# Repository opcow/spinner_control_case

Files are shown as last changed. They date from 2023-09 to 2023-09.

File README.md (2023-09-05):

# Spinner Control Case

A case for a spinner control for retro arcade games. A work in progress.

The case lid can be flipped for right handed or left handed spinner operation. The button assembly uses micro switches taken from an old mouse. RIP MX518. You served me well.

All parts were printed with a 0.4 mm nozzle. All holes were sized for threaded inserts for M3 and M2.5 screws. STEP files are provided if you need to make adjustments.

I've included a fit test model for the microswitch slots that can be printed before printing the full microswitch carrier. You want the switch to fit snugly, but bear in mind that if it the fit is really tight then it's going to force the sides of the slot outward making the adjacent slots even tighter.

The optical encoder I used does not tolerate less that 5v input. My Arduino was supplying a bit under 5v and I was testing using the full length leads to the encoder. When testing without the boost converter the encoder did not work. My converter output is set to 8v.

## Optional Things

I chose to mount the MCU with header pins installed because it helps to hold it solidly in place. The MCU gets sandwiched between the MCU cover and the mount which is screwed to the bottom cover and the whole thing is held together using a zip tie. There is also a mount meant to be used without the cover, just a zip tie holding the board in place. If you use a different MCU than the one I used then you may need to make your own solution for mounting.

Likewise, the front cover is designed to fit my MCU. Modify if needed.

There is a mount with cover for the booster to snap into, but these things come in various shapes. I don't use the cover and I stick the mount to the bottom case cover with a 3M double-sided stickie. You could just stick the booster directly to the bottom cover.

If you don't use threaded inserts then you will want to resize the holes. For quality heat set inserts and tools I recommend [CNC Kitchen](https://www.cnckitchen.com/) (I am not affiliated). They sell quality products and ship promptly in my experience.

There are 2 bottom cover options. The thinner one saves 3mm. The thicker one should be able to accommodate the encoder without its case removed, but you will probably need to rotate the encoder screw holes to avoid interference. I recommend removing the encoder's metal case; it just makes everything easier and you can verify the wiring that way.

## Firmware

The firmware running on the spinner is based on [Wilfried JEANNIARD's repo](https://github.com/willoucom/Arduino_ArcadeSpinner), modified to allow the spinner to act as a DPAD. While holding down button 1 press button 4 then release both buttons. There will be a 1 second delay and then scroll mode will be toggled. While in scroll mode the spinner will send `DPAD UP` presses to the host when turned clockwise and `DPAD DOWN` presses when turned counter-clockwise. While holding button 4 the spinner will send `DPAD RIGHT` and `DPAD LEFT`.

To configure the spinner in the MiSTer UI do the following:

* Toggle scroling mode on
* Using a keyboard, enter the `define joystick buttons` function
* Hold button 4 on the spinner when asked to press `RIGHT` and turn the spinner CW
* When asked to press `DOWN`, release button 4 and turn the spinner counter-clockwise
* Skip the 2 tilt tests
* Hold button 4 and turn the spinner CW then CCW to define `RIGHT` AND `LEFT`
* Release button 4 then turn the spinner CCW then CW to define `DOWN` and `UP`
* Toggle scrolling mode off
* Press and release buttons 1-4 to define `A`, `B`, `X`, and `Y`
* Press enter on the keyboard to save the configuration

If you mess up during these steps press escape and try again.

## Links for parts I purchased for this project

* [Optical encoder](https://www.amazon.com/dp/B07MX1SYXB?ref=ppx_yo2ov_dt_b_product_details&th=1)
* [A less expensive optical encoder which should also work](https://www.amazon.com/dp/B00UTIFCVA/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)
* [Boost converter](https://www.amazon.com/dp/B0C858YYQ1?ref=ppx_yo2ov_dt_b_product_details&th=1)
* [Type-C USB Pro Micro ATmega32U4 5V 16MHz](https://www.amazon.com/dp/B0BCW67NJP?psc=1&ref=ppx_yo2ov_dt_b_product_details)

---
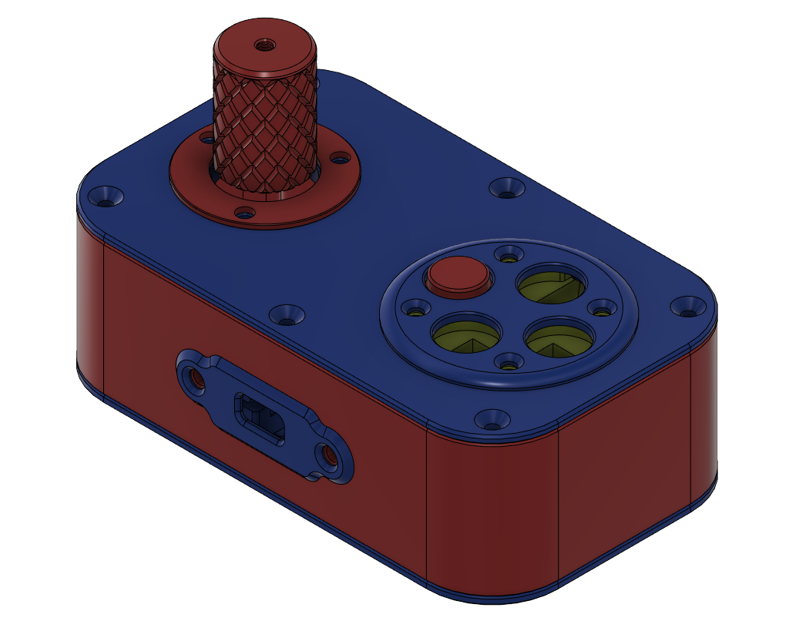
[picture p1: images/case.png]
case image

---
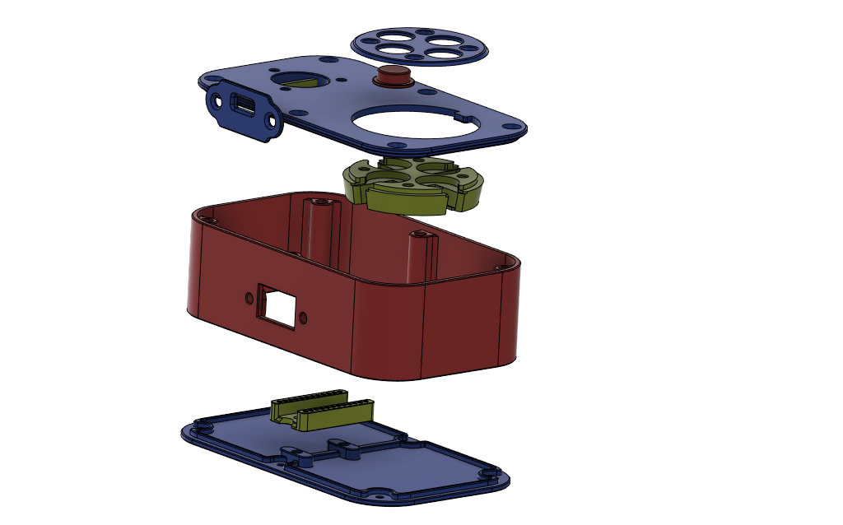
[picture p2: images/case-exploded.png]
exploded view

---
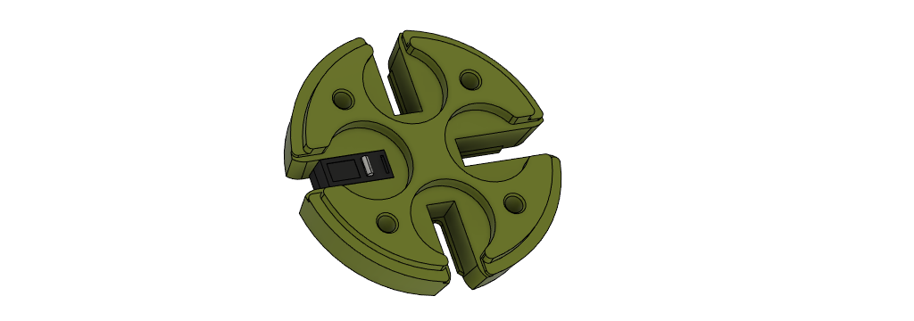
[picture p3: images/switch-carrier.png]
switch carrier

---
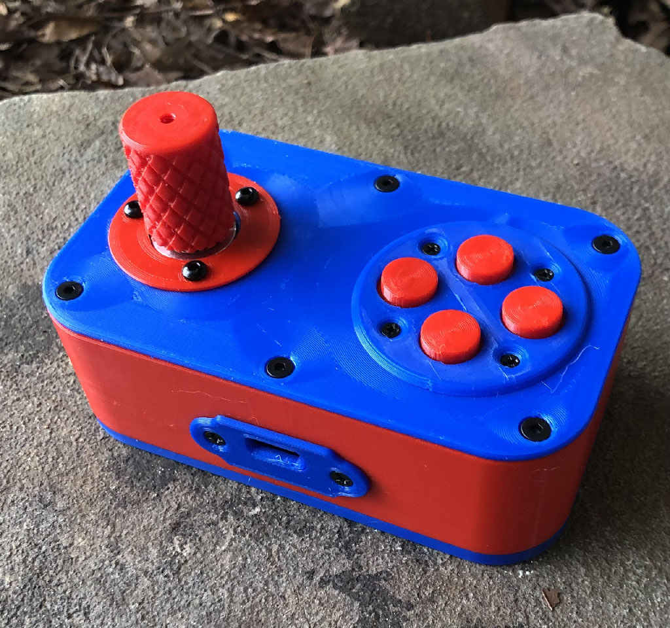
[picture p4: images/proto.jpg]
prototype


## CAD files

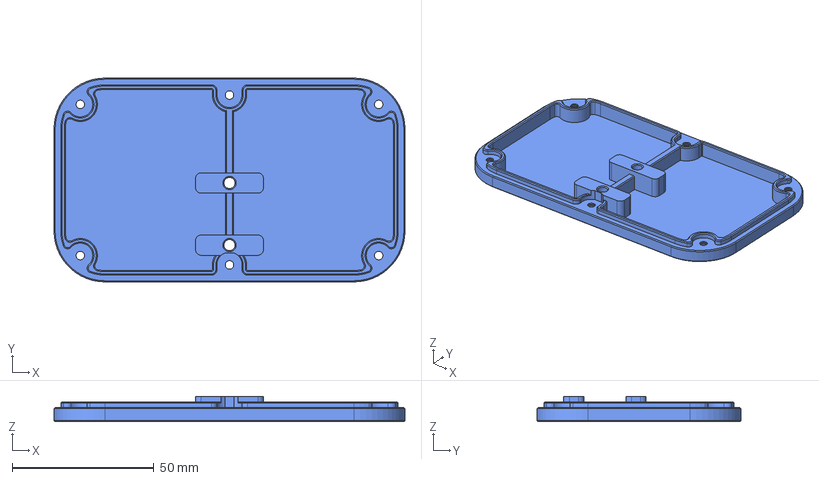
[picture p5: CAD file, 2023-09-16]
STEP/bottom-cover-a.step
124.0 x 72.0 x 9.00 mm

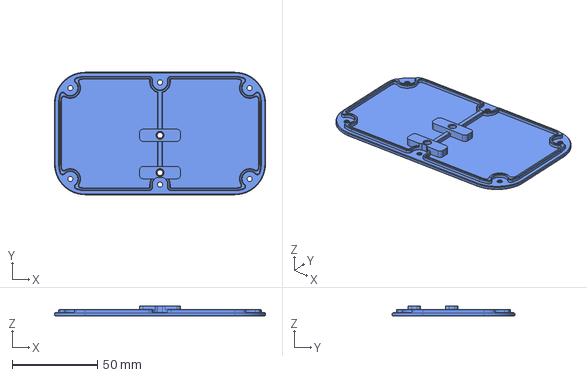
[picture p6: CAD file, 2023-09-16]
STEP/bottom-cover-b.step
124.0 x 72.0 x 6.00 mm

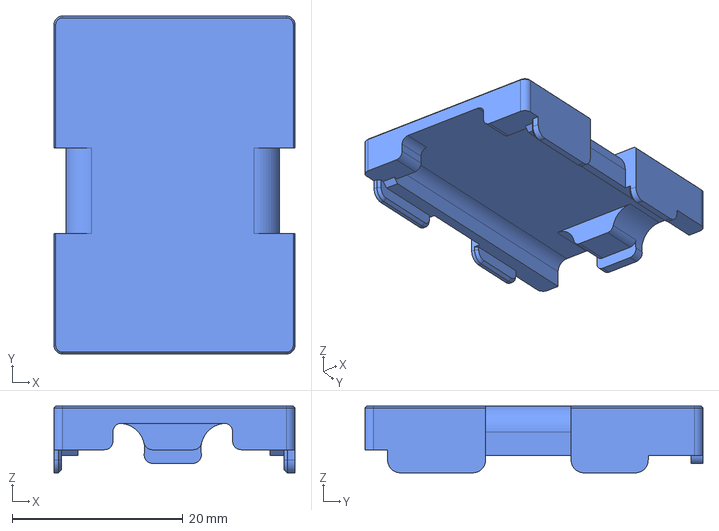
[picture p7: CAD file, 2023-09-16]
STEP/mcu-mount-c-cover.step
28.2 x 39.5 x 7.80 mm

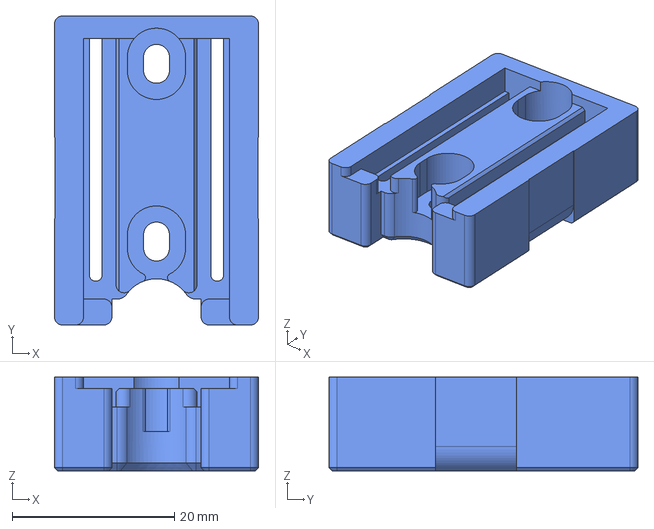
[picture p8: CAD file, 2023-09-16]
STEP/mcu-mount-c.step
25.2 x 38.1 x 11.6 mm

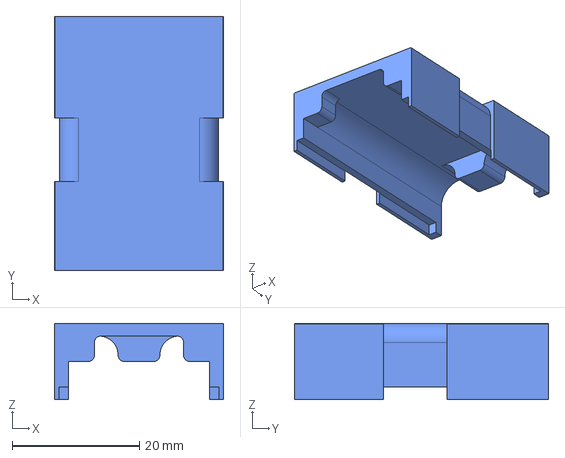
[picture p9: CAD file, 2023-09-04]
STEP/mcu-mount-b-cover.step
26.6 x 39.9 x 12.0 mm

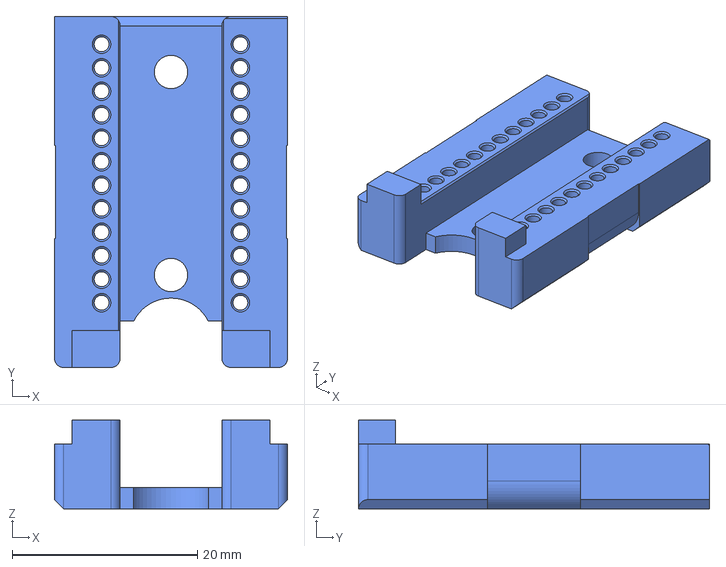
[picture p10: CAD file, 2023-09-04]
STEP/mcu-mount-b.step
25.2 x 37.9 x 9.60 mm

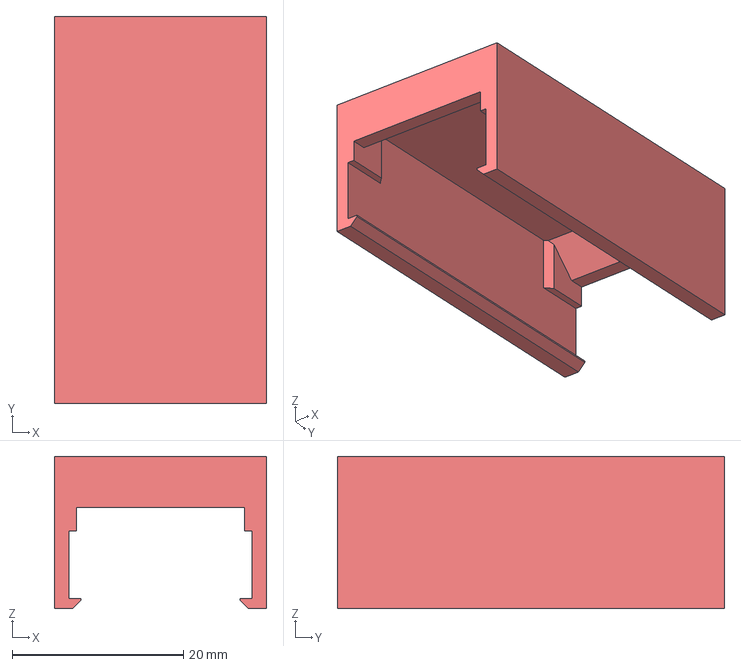
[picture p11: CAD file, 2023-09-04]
STEP/booster-cover.step
24.8 x 45.2 x 17.8 mm

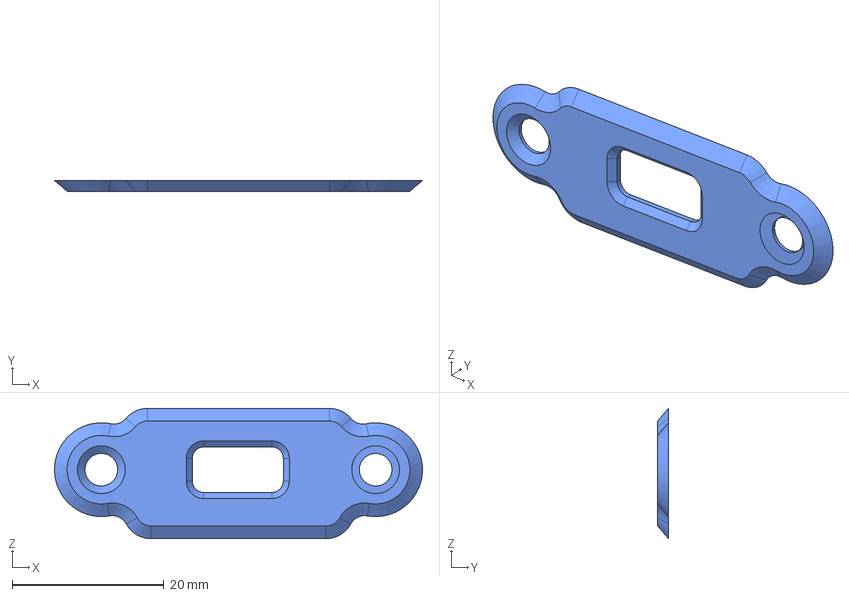
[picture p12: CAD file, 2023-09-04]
STEP/front-cover.step
48.6 x 1.40 x 17.2 mm

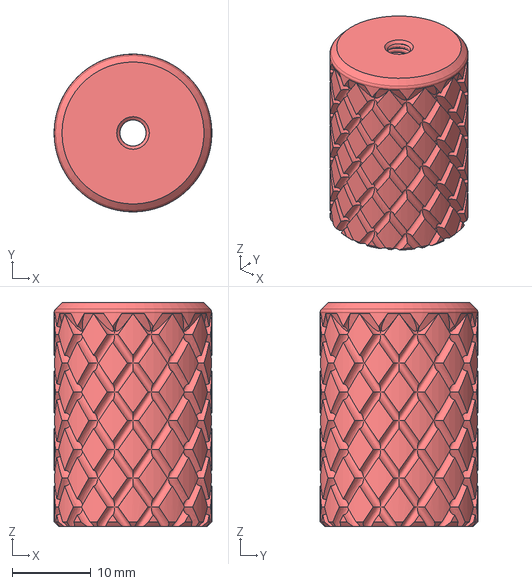
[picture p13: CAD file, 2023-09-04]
STEP/20mm-knob.step
20.0 x 20.0 x 28.4 mm

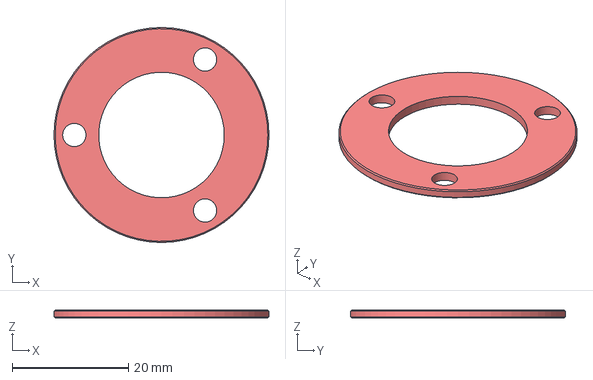
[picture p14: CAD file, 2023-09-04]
STEP/knob-ring.step
37.0 x 37.0 x 1.40 mm

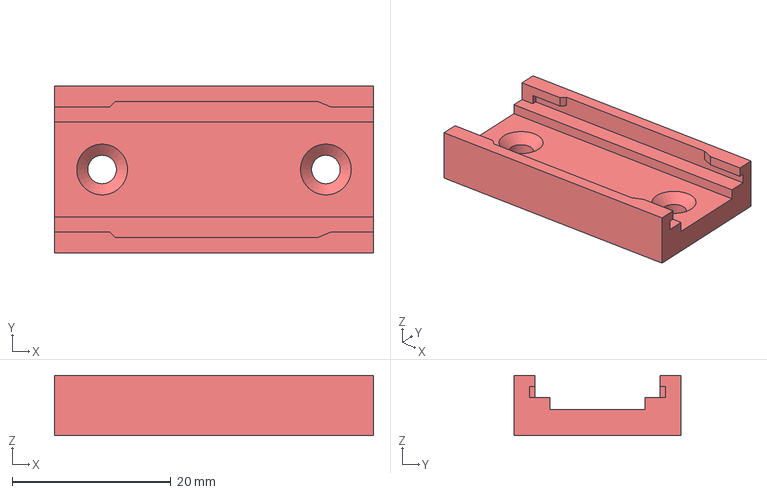
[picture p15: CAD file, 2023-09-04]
STEP/booster-mount.step
40.2 x 21.0 x 7.60 mm

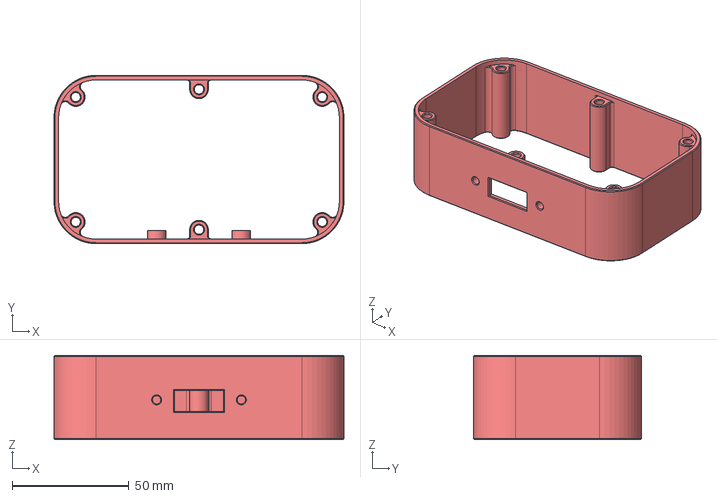
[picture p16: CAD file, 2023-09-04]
STEP/case.step
124.0 x 72.0 x 36.0 mm

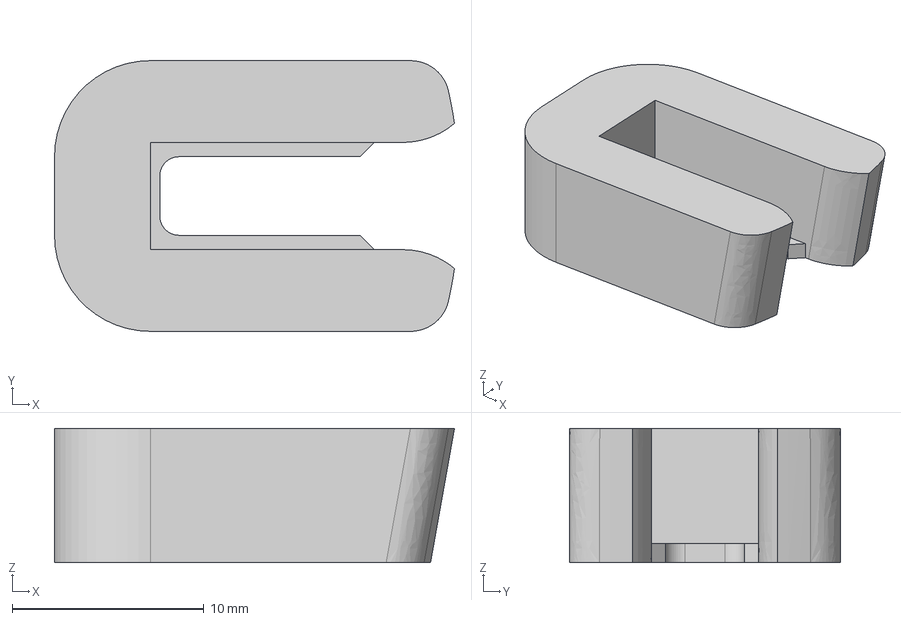
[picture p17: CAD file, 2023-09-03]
STEP/fit-test.step
20.9 x 14.1 x 7.00 mm

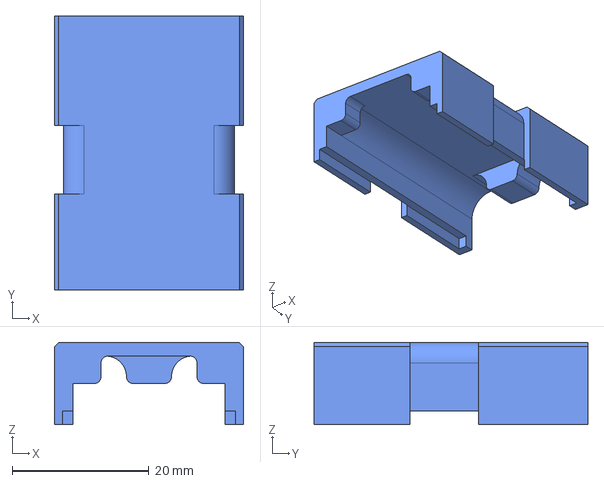
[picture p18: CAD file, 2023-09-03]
STEP/board-mount-b-cover.step
27.6 x 39.9 x 12.0 mm

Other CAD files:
STEP/mcu-mount-a.step
STEP/board-mount-b.step
STEP/button-cover.step
STEP/microswitch-carrier.step
STEP/12mm-button.step
STEP/top-cover.step
STL/12mm-button.stl
STL/booster-cover.stl
STL/booster-mount.stl
STL/bottom-cover-a.stl
STL/bottom-cover-b.stl
STL/button-cover.stl
STL/case.stl
STL/fit-test.stl
STL/front-cover.stl
STL/knob-ring.stl
STL/mcu-mount-a.stl
STL/mcu-mount-b-cover.stl
STL/mcu-mount-b.stl
STL/mcu-mount-c-cover.stl
STL/mcu-mount-c.stl
STL/microswitch-carrier.stl
STL/top-cover.stl
booster_mount.step
front_cover.step

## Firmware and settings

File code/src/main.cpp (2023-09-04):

/*
 *  Arduino USB Arcade Spinner
 *  (C) Wilfried JEANNIARD [https://github.com/willoucom]
 *
 *  Based on project by Alexey Melnikov [https://github.com/MiSTer-devel/Retro-Controllers-USB-MiSTer/blob/master/PaddleTwoControllersUSB/PaddleTwoControllersUSB.ino]
 *  Based on project by Mikael Norrgård <mick@daemonbite.com>
 *
 *  GNU GENERAL PUBLIC LICENSE
 *  Version 3, 29 June 2007
 *
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
 */

///////////////// Customizable settings /////////////////////////
// For debug (check serial monitor)
// #define DEBUG

// Spinner pulses per revolution
#define SPINNER_PPR 600

// Spinner/Mouse sensitivity
// 1 is more sensitive
// 999 is less sensitive
#define SPINNER_SENSITIVITY 2
#define MOUSE_SENSITIVITY 4

/////////////////////////////////////////////////////////////////

// Pins used by encoder
#define pinA 2
#define pinB 3
// Pins used by buttons
#define Button0 5  // Left button
#define Button1 4  // Right button
#define Button2 15 // Small Left: Select/Coin
#define Button3 14 // Small Right: Start

////////////////////////////////////////////////////////

// ID for special support in MiSTer
// ATT: 20 chars max (including NULL at the end) according to Arduino source code.
// Additionally serial number is used to differentiate arduino projects to have different button maps!
const char *gp_serial = "MiSTer-A1 Spinner";

#include <Mouse.h>
#include "Gamepad.h"

// Create Gamepad
Gamepad_ Gamepad;
GamepadReport rep;

// Default virtual spinner position
int16_t drvpos = 0;
// Default real spinner position
int16_t r_drvpos = 0;
// Default virtual mouse position
int16_t m_drvpos = 0;

// Variables for paddle_emu
#define SP_MAX ((SPINNER_PPR * 4 * 270UL) / 360)
int32_t sp_clamp = SP_MAX / 2;

// For emulation
bool mouse_emu = 0;
bool paddle_emu = 0;
bool mr_spinner_emu = 0;
bool scroll_mode = false;

void scroll(int16_t dir);

// Interrupt pins of Rotary Encoder
void drv_proc()
{
  static int8_t prev = drvpos;
  int8_t a = digitalRead(pinA);
  int8_t b = digitalRead(pinB);

  int8_t spval = (b << 1) | (b ^ a);
  int8_t diff = (prev - spval) & 3;

  if (diff == 1)
  {
    r_drvpos += 1;
    if (sp_clamp < SP_MAX)
      sp_clamp++;
  }
  if (diff == 3)
  {
    r_drvpos -= 1;
    if (sp_clamp > 0)
      sp_clamp--;
  }

  drvpos = r_drvpos / SPINNER_SENSITIVITY;
  m_drvpos = r_drvpos / MOUSE_SENSITIVITY;
  prev = spval;
}

// Run at startup
void setup()
{
  pinMode(LED_BUILTIN_TX, INPUT);
  pinMode(LED_BUILTIN_RX, INPUT);
#ifdef DEBUG
  Serial.begin(9600);
#endif
  Gamepad.reset();

  // Encoder
  pinMode(pinA, INPUT_PULLUP);
  pinMode(pinB, INPUT_PULLUP);
  // Init encoder reading
  drv_proc();
  // Attach interrupt to each pin of the encoder
  attachInterrupt(digitalPinToInterrupt(pinA), drv_proc, CHANGE);
  attachInterrupt(digitalPinToInterrupt(pinB), drv_proc, CHANGE);

  // Initialize Button Pins
  pinMode(Button0, INPUT_PULLUP);
  pinMode(Button1, INPUT_PULLUP);
  pinMode(Button2, INPUT_PULLUP);
  pinMode(Button3, INPUT_PULLUP);

  // Spinner only (AKA mr.Spinner mode)
  if (!digitalRead(Button0) && !digitalRead(Button1))
  {
    // Announce the device as mr.Spinner (more explanations in the readme file)
    mr_spinner_emu = !mr_spinner_emu;
    gp_serial = "MiSTer-S1 Spinner";
  }
  else
  {
    // Enable mouse emulation
    if (!digitalRead(Button0))
    {
      mouse_emu = !mouse_emu;
      Mouse.begin();
    }
    // Enable paddle emulation
    if (!digitalRead(Button1))
    {
      paddle_emu = !paddle_emu;
    }
  }
}

// Main loop
void loop()
{
  // Default Spinner/Paddle position;
  rep.paddle = 0;
  rep.spinner = 0;

  // Buttons
  if (mr_spinner_emu)
  {
    rep.b0 = !digitalRead(Button0) || !digitalRead(Button1) || !digitalRead(Button2) || !digitalRead(Button3);
  }
  else
  {
    rep.b0 = !digitalRead(Button0);
    rep.b1 = !digitalRead(Button1);
    rep.b2 = !digitalRead(Button2);
    // b3 is used for horiz scrolling in scroll mode
    if (!scroll_mode)
    {
      rep.b3 = !digitalRead(Button3);
      rep.x_axis = 127;
      rep.y_axis = 127;
    }
  }

  // scroll mode combo
  if (!digitalRead(Button0) && !digitalRead(Button3))
  {
    scroll_mode = !scroll_mode;
    while (!digitalRead(Button0) || !digitalRead(Button3))
      delay(50);
    rep.x_axis = 127;
    rep.y_axis = 127;
    rep.b0 = 0;
    rep.b1 = 0;
    rep.b2 = 0;
    rep.b3 = 0;
    delay(1000);
  }

  static unsigned long otime = 0;
  unsigned long ntime;

  if (scroll_mode)
  {
    ntime = millis();
    if ((ntime - otime) > 50)
    {
      scroll(drvpos);
      otime = ntime;
    }
  }

  // spinner rotation
  static uint16_t prev = 0;
  int16_t val = ((int16_t)(drvpos - prev));

  if (val > 127)
    val = 127;
  else if (val < -127)
    val = -127;
  rep.spinner = val;
  rep.spinner = val;
  prev += val;

  // Paddle Emulation
  if (paddle_emu)
  {
    rep.paddle = ((sp_clamp * 255) / SP_MAX);
    rep.spinner = 0;
  }

  // Mouse Emulation
  if (mouse_emu)
  {
    static uint16_t m_prev = 0;
    int16_t val = ((int16_t)(m_drvpos - m_prev));
    if (val > 127)
      val = 127;
    else if (val < -127)
      val = -127;
    m_prev += val;
    Mouse.move(val, 0);
    rep.spinner = 0;
  }

  // Only report controller state if it has changed
  if (memcmp(&Gamepad._GamepadReport, &rep, sizeof(GamepadReport)))
  {
#ifdef DEBUG
    // Very verbose debug
    Serial.print(gp_serial);
    Serial.print(" ");
    Serial.print(drvpos);
    Serial.print(" ");
    Serial.print(mouse_emu);
    Serial.print(" ");
    Serial.print(paddle_emu);
    Serial.print(" ");
    Serial.print(rep.spinner);
    Serial.print(" ");
    Serial.print(rep.paddle);
    Serial.print(" ");
    Serial.print(rep.b0);
    Serial.print(" ");
    Serial.print(rep.b1);
    Serial.print(" ");
    Serial.print(rep.b2);
    Serial.print(" ");
    Serial.println(rep.b3);
#endif
    // Send Gamepad changes
    Gamepad._GamepadReport = rep;
    Gamepad.send();
  }
}

void scroll(int16_t pos)
{
#define DEAD_ZONE 10

  static bool pressed = false;
  static int16_t prev = 0;
  int16_t delta = pos - prev;

  if (!pressed)
  {
    if (!digitalRead(Button3))
    {
      if (delta < -DEAD_ZONE)
        rep.x_axis = 0;
      else if (delta > DEAD_ZONE)
        rep.x_axis = 255;
    }
    else
    {
      if (delta > DEAD_ZONE)
        rep.y_axis = 0;
      else if (delta < -DEAD_ZONE)
        rep.y_axis = 255;
    }
    prev = pos;
  }
  else
  {
    rep.x_axis = 127;
    rep.y_axis = 127;
  }
  pressed = !pressed;
}

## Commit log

2023-09-02 add step files
    [12mm-button.step, board_mount.step, booster_mount.step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]
2023-09-02 added fit test part
    [fit-test.step]
2023-09-02 thickened button cover to reduce flex
    [button-cover.step]
2023-09-04 refactor scroll function
    [case.step]
2023-09-04 prototype and knob
    [20mm-knob.step]
2023-09-04 added knob and other accessories
    [20mm-knob.step, booster-cover.step, booster-mount.step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]
2023-09-04 renamed models
    [board-mount-a.step, mcu-mount-a.step, mcu-mount-b-cover.step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]
2023-09-04 add stl files
    [12mm-button.stl, booster-cover.stl, booster-mount.stl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]
2023-09-04 fix file name
    [case.stl]
2023-09-16 new arduino mount option
    [mcu-mount-c-cover.step, mcu-mount-c-cover.stl, mcu-mount-c.step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]
2023-09-16 insert holes revised to M3 size
    [bottom-cover-a.step, bottom-cover-a.stl, bottom-cover-b.step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]

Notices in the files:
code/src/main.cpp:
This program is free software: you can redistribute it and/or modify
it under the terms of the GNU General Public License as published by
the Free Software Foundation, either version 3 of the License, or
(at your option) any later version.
